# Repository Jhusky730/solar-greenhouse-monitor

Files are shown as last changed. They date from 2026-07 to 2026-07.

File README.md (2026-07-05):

# Solar-Powered Environmental & Soil Monitor

An ultra-low-power ESP32-C3 environmental telemetry node with solar harvesting and deep sleep optimization.

## Project Info

This project is a monnitor for my greenhouse. It can measure:
- Soil Moisture
- Humidity
- Air Temperature

This will allow me to take better care of my plants, and hopefully achieve a higher yield.

I was inspired to create this project after seeing a video of a fully automated greenhouse, so I attempted to partially replicate it myself.

## Photos





## Implementation, Topology, and Assembly Reference

The custom PCB routes the ESP32-C3-WROOM-02U peripherals to external components using these net configurations:
* **USB Native Data (-)**: GPIO18 (IO18) at J4 (A7/B7) for native flashing.
* **USB Native Data (+)**: GPIO19 (IO19) at J4 (A6/B6) for native flashing.
* **I2C Data (SDA)**: GPIO2 (IO2) at J2 (Pin 3) for the SHT41 sensor port.
* **I2C Clock (SCL)**: GPIO10 (IO10) at J2 (Pin 4) as an overridden clock channel.
* **Analog Soil Signal**: GPIO1 (IO1) at J3 (Pin 3) via ADC1_CH1 for 12-bit sampling.
* **Boot Mode Strap**: GPIO9 (IO9) at R1/R3 pulled to 3V3 with a 10k Ohm resistor for flash boot.

The power system regulates input voltages to protect the 6V-maximum AP2112K regulator and the ESP32-C3. A 9V 600mA solar panel feeds a Waveshare Power Manager to charge a 3.7V 1200mAh LiPo battery and supply a stable 5V 3A rail to PCB terminal J1. Current flows through an SS14L Schottky diode (D1)—dropping voltage to ~4.6V—before entering the AP2112K regulator (U1) to distribute a stable 3.3V power plane.

Verify the board assembly matches this functional checklist before power activation:
1. **Polarization (C1)**: The printed stripe on the Kyocera AVX Tantalum capacitor must face away from Ground and connect to the +5V rail.
2. **Directional Flow (D1)**: The printed cathode stripe on the SS14L Schottky diode must point toward the filtering capacitors (C1/C2) and away from the J1 input block.
3. **USB Verification**: Connecting J4 via a data-rated Type-C cable must natively enumerate an *ESP32-C3 USB Serial/JTAG Controller* without manual driver installation.

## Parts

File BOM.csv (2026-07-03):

Item | Quantity | Source | Part Number / Link | Manufacturer | MPN | Description | Package / Form Factor | Designator / Notes
1 | 1 | LCSC | C2926676 | ESPRESSIF | ESP32-C3-WROOM-02U-N4 | 2.4GHz ESP32-C3 Module (U.FL External Antenna) | SMD-19P | U2
2 | 5 | LCSC | C165948 | Korean Hroparts Elec | TYPE-C-31-M-12 | USB-C Receptacle 16 Position | SMD (16-Pin) | J4
3 | 1 | LCSC | C916292 | MOLEX | 1461530050 | Flexible RF Antenna with U.FL/MHF Connector | Chassis Mount | ANT14
4 | 1 | LCSC | C148107 | Kyocera AVX | TPSB107M010R0400 | 100uF ±20% 10V Tantalum Capacitor 400mΩ | CASE-B-3528-21 | C1 (Stripe AWAY from GND)
5 | 100 | LCSC | C108451 | Walsin | WR08X1002FTL | 125mW 10kΩ Thick Film Resistor ±1% | 0805 | R1 R3 (Boot/Reset Pull-up)
6 | 100 | LCSC | C84375 | YAGEO | RC0805FR-075K1L | 5.1kΩ 125mW Thick Film Resistor ±1% | 0805 | R2 R4 (USB-C CC Pull-down)
7 | 10 | LCSC | C83055 | Walsin | 0805B104K500CT | 100nF ±10% 50V Ceramic Capacitor X7R | 0805 | C2 C4
8 | 20 | LCSC | C99915 | Walsin | 0805B105K500CT | 1uF ±10% 50V Ceramic Capacitor X7R | 0805 | C3
9 | 10 | LCSC | C125883 | PANJIT | SS14L_R1_00001 | Schottky Diode 40V 1A Surface Mount | SMA (DO-214AC) | D1 (Stripe TOWARD Caps)
10 | 5 | LCSC | C474952 | Cixi Kefa Elec | KF128-5.08-2P-AA | 2 Pos Wire to Board Terminal Block 5.08mm | Through Hole 5.08mm | J1 (Power Input)
11 | 5 | LCSC | C22365427 | MSKSEMI | AP2112K-3.3TRG1(MS) | Linear Voltage Regulator IC Fixed 3.3V 600mA | SOT-23-5 | U1
12 | 10 | LCSC | C5445396 | CJT | A2541WV-3P | Pin Header 3 Position 2.54mm Single Row | Through Hole 2.54mm | J3 (Moisture Expansion)
13 | 5 | LCSC | C160404 | JST | SM04B-SRSS-TB(LF)(SN) | Connector Header 4 position 1mm Pitch 1A R/A | SMD Right Angle 1mm | J2 (Qwiic / STEMMA QT)
14 | 20 | LCSC | C42393300 | XFCN | XF7126 | UL1007 22AWG Red Stranded Hookup Wire (100mm) | Pre-cut Lead | Positive Power Paths
15 | 20 | LCSC | C42393303 | XFCN | XF7129 | UL1007 22AWG Black Stranded Hookup Wire (100mm) | Pre-cut Lead | Ground Return Loops
16 | 1 | Pi Hut | https://thepihut.com | Adafruit | ADA4209 | QT / Qwiic JST-SH 4-pin to Male Jumpers (150mm) | Wire Harness | Connects J2 to SHT41 Breakout
17 | 1 | Pi Hut | https://thepihut.com | PKCell | TTPH-LIPO-1200 | 3.7V LiPo Battery (JST-PH) | Battery Pack | Plugs into Waveshare Manager
18 | 1 | Pi Hut | https://thepihut.com | Waveshare | WS-16120 | Power Manager Module (6V-24V) | Pre-assembled Board | Steps down Panel to safe 5V/3A Output
19 | 1 | Pi Hut | https://thepihut.com | Pi Hut | TTPH-SOLAR-9V | Solar Panel (9v 600mA) | Chassis Panel | Powers Waveshare Manager Input
20 | 1 | Pi Hut | https://thepihut.com | Pi Hut | TTPH-SOIL-MOIST | Capacitive Soil Moisture Sensor | Probe Module | Plugs into J3 via included Female cable
21 | 1 | Pi Hut | https://thepihut.com | Sensirion | SHT41 | SHT41 Temp & Humidity Sensor, Breakout Board | Module | Plugs into J2 QT port via item 16
22 | 2 | AliExpress | Moonlight electric | PG7-PG19-MIX | Nylon Cable Glands | 10Pcs Nylon Cable Glands IP68 (PG7/PG9 Assortment) | Hardware Pack | Enclosure Access Ports
23 | 1 | AliExpress | FEITA Tools Store | FEITA-80W-KIT | Soldering Iron Kit | 80W LCD Digital Soldering Iron Kit (UK Plug) | Tooling Set | Assembly Tools
24 | 1 | AliExpress | Wenzhou Xiangheng | IP67-ABS-BLK | Waterproof Box | ABS Waterproof Box Housing Safe Case (Black) | Junction Box | Main Enclosure

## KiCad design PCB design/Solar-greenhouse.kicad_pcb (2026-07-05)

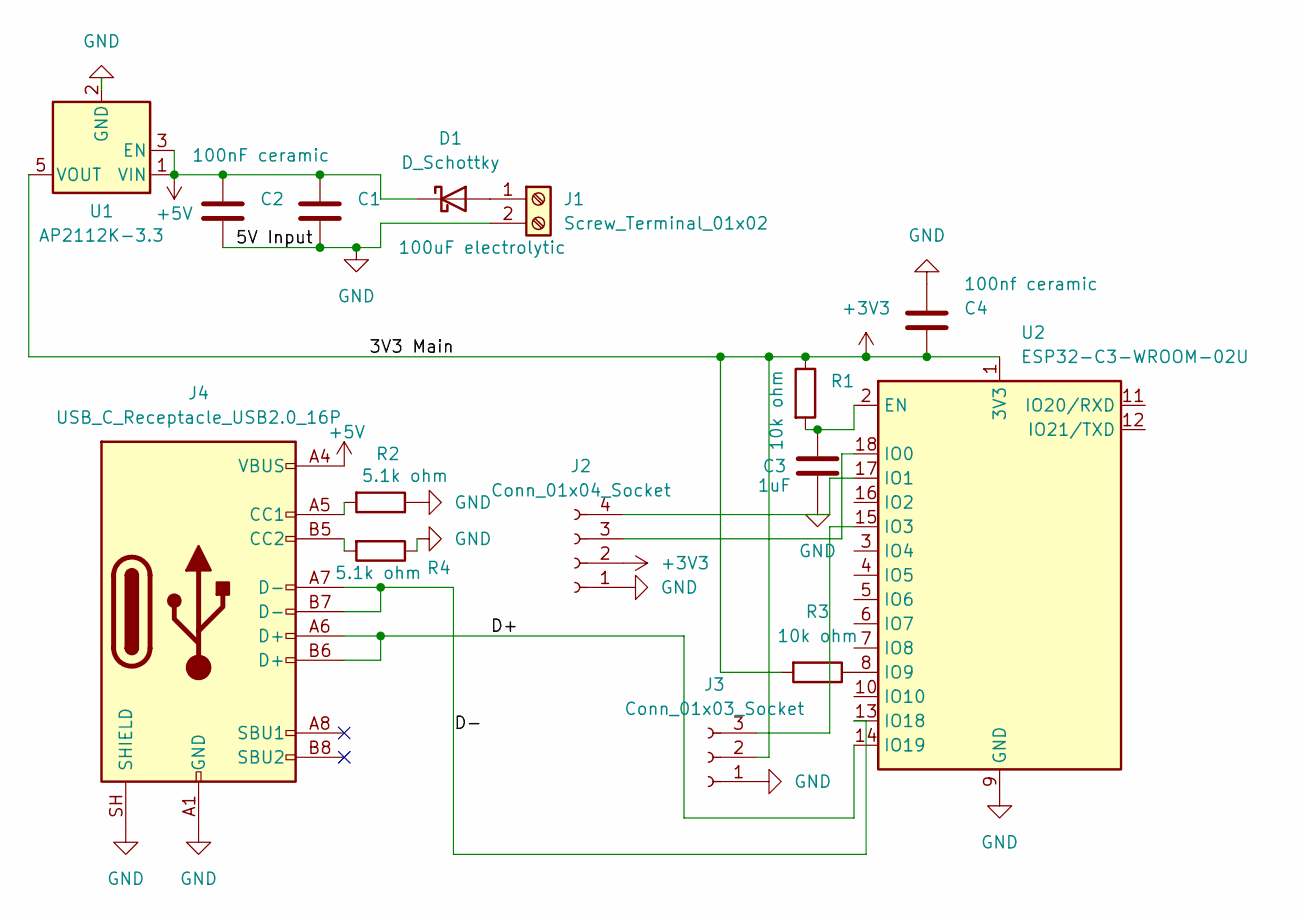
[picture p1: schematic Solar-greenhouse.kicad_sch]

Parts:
C1: 100uF electrolytic; CP_EIA-3528-21_Kemet-B_HandSolder
C2: 100nF ceramic; C_0805_2012Metric
C3: 1uF; C_0805_2012Metric
C4: 100nf ceramic; C_0805_2012Metric
D1: D_Schottky; D_SMA_Handsoldering
J1: Screw_Terminal_01x02; TerminalBlock_Phoenix_MKDS-1,5-2-5.08_1x02_P5.08mm_Horizont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
J2: Conn_01x04_Socket; JST_SH_SM04B-SRSS-TB_1x04-1MP_P1.00mm_Horizontal
J3: Conn_01x03_Socket; PinHeader_1x03_P2.54mm_Vertical
J4: USB_C_Receptacle_USB2.0_16P; USB_C_Receptacle_HRO_TYPE-C-31-M-12
R1, R3: 10k ohm; R_0805_2012Metric
R2, R4: 5.1k ohm; R_0805_2012Metric
U1: AP2112K-3.3; SOT-23-5
U2: ESP32-C3-WROOM-02U

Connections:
+3V3: C4.1, J2.2, J3.2, R1.1, R3.2, U1.5 (VOUT), U2.1 (3V3)
+5V: C1.1, C2.1, D1.1 (K), J4.A4 (VBUS), J4.A9 (VBUS), J4.B4 (VBUS), J4.B9 (VBUS), U1.1 (VIN), U1.3 (EN)
GND: C1.2, C2.2, C3.2, C4.2, J1.2, J2.1, J2.MP, J3.1, J4.A1 (GND), J4.A12 (GND), J4.B1 (GND), J4.B12 (GND), J4.SH (SHIELD), R2.1, R4.1, U1.2 (GND), U2.9 (GND), U2.19 (GND)
unnamed: D1.2 (A), J1.1
unnamed: J2.3, U2.18 (IO0)
unnamed: J2.4, U2.17 (IO1)
unnamed: J3.3, U2.15 (IO3)
unnamed: J4.A5 (CC1), R2.2
unnamed: J4.B5 (CC2), R4.2
unnamed: C3.1, R1.2, U2.2 (EN)
unnamed: R3.1, U2.8 (IO9)
unnamed: J4.A7 (D-), J4.B7 (D-), U2.13 (IO18)
unnamed: J4.A6 (D+), J4.B6 (D+), U2.14 (IO19)

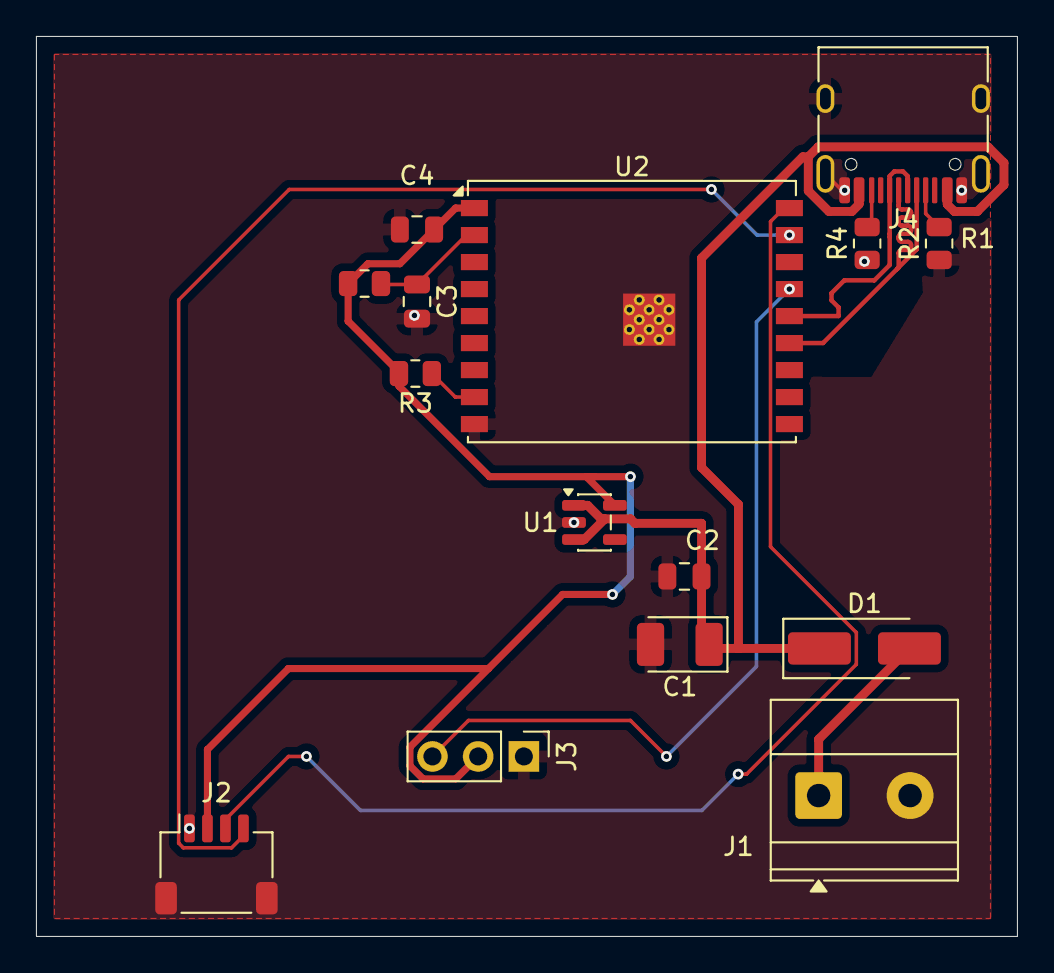
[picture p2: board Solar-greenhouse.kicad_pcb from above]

Board: 2 copper layers, 54.5 x 50.0 mm, 15 parts (0 on the bottom side), 13 nets.

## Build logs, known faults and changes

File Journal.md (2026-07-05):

# July 2nd

I have designed the PCB for my Greenhouse monitor.
It includes:
- An ESP32-C3-WROOM-O2U to control the system
- An AP2112k-3.3 for regulating the 5V input to 3V3
- A 1x2 Screw Terminal to connect the solar power system
- A USB C Receptacle for uploading the program
- A JST_SH socket for connecting the temperature and humidity sensor
- A 1x3 header to connect the soil moisture sensor.



# July 5th

I have improved upon my design as according to the reviewer.
I have:
- Moved the USB and JST_SH inputs closer to the edge of the board (There is no Shcottky diode on the USB input as i will not be plugging in both the solar and USB at the same time)
- Wired the USB D+ and D- pins differentially
- Connected the USB VBUS to the regulator
- Increased the size of the trace from the Screw Terminal to the Schottky diode.
- Added net labels for some nets



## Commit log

2026-07-01 Revise README with detailed project information
    Updated project description and added detailed sections on power management, wiring plan, and safety measures for outdoor use.
2026-07-01 Add Bill of Materials (BOM) CSV file
    [BOM.csv]
2026-07-02 Revise README for Solar ESP32-C3 Sensor project
    Updated project description and added hardware details.
2026-07-02 Add new components to BOM.csv
    Updated BOM.csv to include new components and specifications.
    [BOM.csv]
2026-07-02 Revise BOM with new components and specifications
    Updated BOM.csv to include additional components and their details.
    [BOM.csv]
2026-07-03 Revise BOM.csv with updated item details and sources
    Updated BOM.csv to include new items and modify existing entries for better clarity and sourcing information.
    [BOM.csv]
2026-07-03 Modify BOM.csv to update and add components
    Updated item descriptions and added missing items with details.
    [BOM.csv]
2026-07-03 Revise README for clarity and detail
    Updated the README to clarify hardware architecture, power delivery system, and implementation details.
2026-07-03 Update BOM.csv with new entries
    [BOM.csv]
2026-07-03 Remove empty line from BOM.csv
    [BOM.csv]
2026-07-03 Fix formatting issue in BOM.csv
2026-07-03 Update BOM.csv with new product descriptions
    [BOM.csv]
2026-07-03 Update product descriptions in BOM.csv
    [BOM.csv]
2026-07-05 Update Journal with PCB design and improvements
    Documented the design and improvements of the PCB for the Greenhouse monitor, including component details and layout changes.
